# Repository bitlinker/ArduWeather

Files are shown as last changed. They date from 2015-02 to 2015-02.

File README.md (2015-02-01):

# ArduWeather
Yet another Arduino weather station project

This project is heading to create the portable device for measuring temperature, humidity and atmospheric pressure inside and outside the house and share that data using USB serial interface.

## Hardware
The hardware used:
* [Arduino](http://arduino.cc/en/Main/ArduinoBoardUno) compatible board (I used Arduino UNO)
* BMP085 pressure sensor with current-limiting resistors
* DHT22 temperature-humidity sensor
* 433 MHz Wireless Receiving Module for Oregon Scientific wireless sensors

The wiring is shown on the image below:
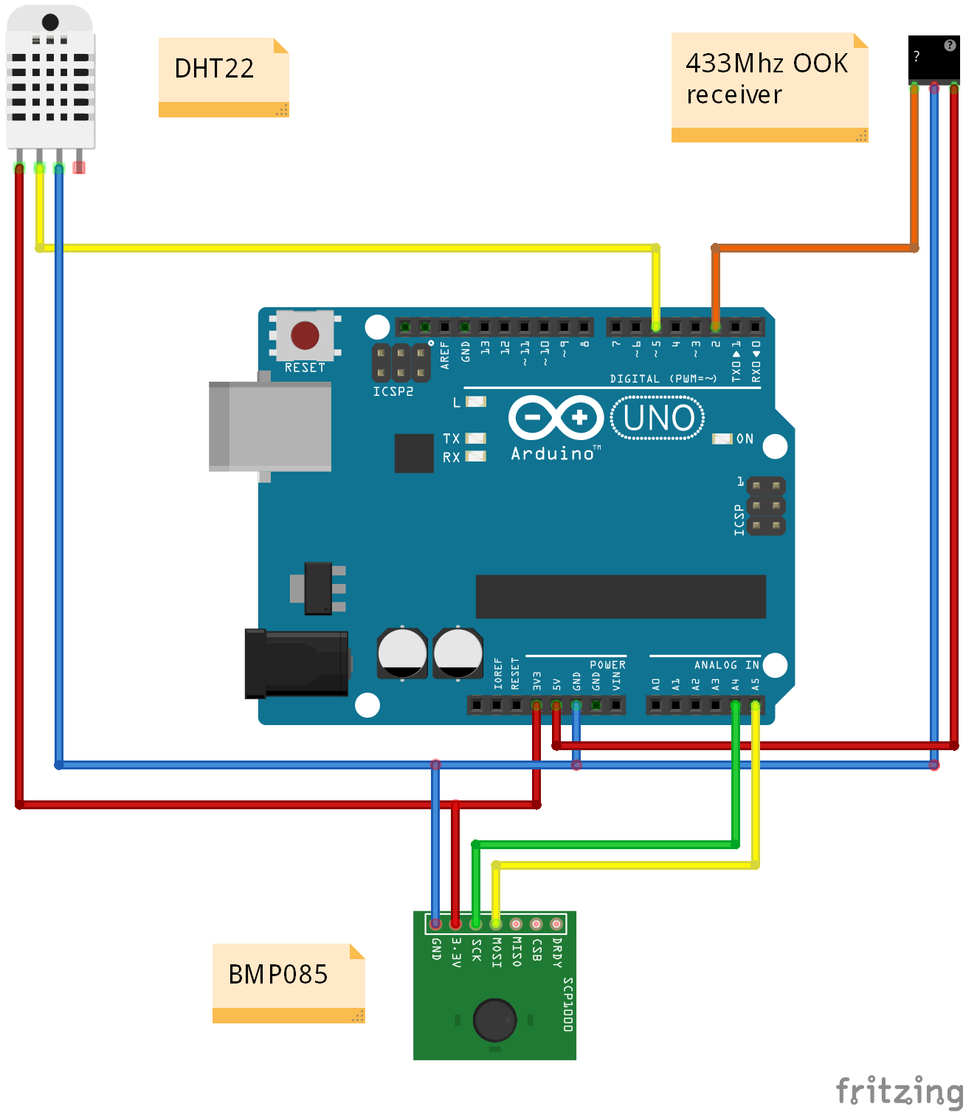
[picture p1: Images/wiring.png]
Wiring


The DHT22 is powered by 5V and it's data out pin is connected to the Arduino D5 pin.
The BMP085 is powered by 3.3V, SDA is connected to A4 and SCL is connected to A5 - hardware I²C bus is used.
The receiver is powered by 5V and connected to D2 - hardware interrupt is used

The 17.3cm wire should be used for antenna on 433 Mhz. It's enough to get good signal from wireless sensor about 15m away blocked by 2 walls. The old modem casing was used. There are some photos of assembled device:
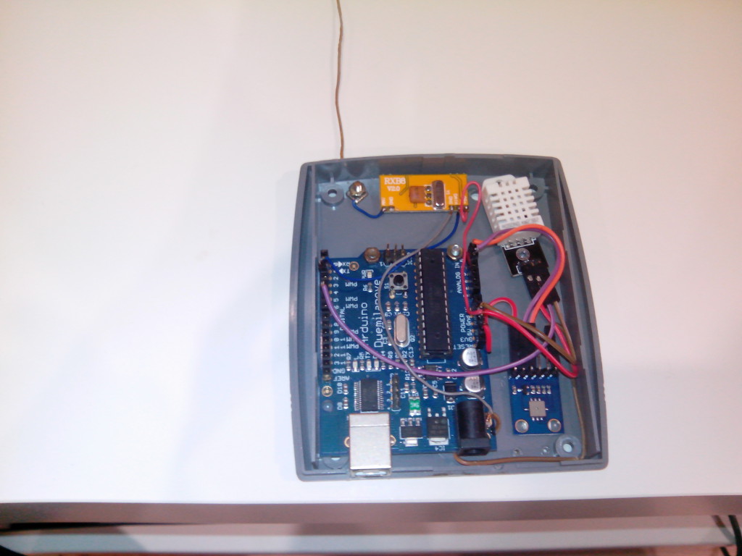
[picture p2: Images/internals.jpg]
Device internals

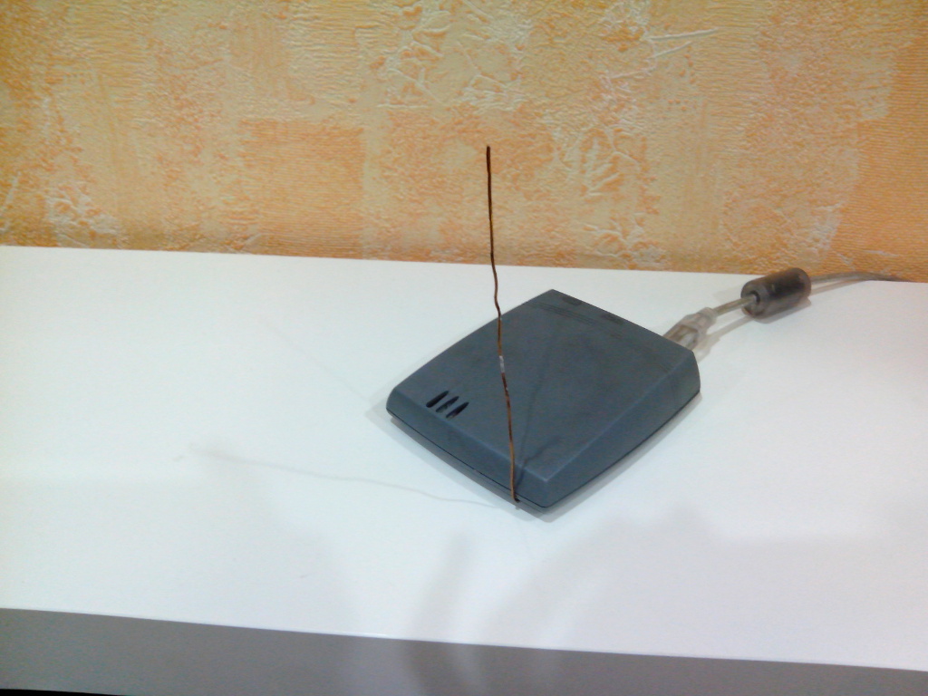
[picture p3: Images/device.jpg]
Assembled device


## Software
The Arduino firmware could be found in repository. The following libraries were used:
* [Adafruit_BMP085](https://github.com/adafruit/Adafruit-BMP085-Library)
* [DhtLib](http://playground.arduino.cc/Main/DHTLib)
* [TimerOne](http://playground.arduino.cc/Code/Timer1) - it was not really necessary, however really convenient.
* [ookDecoder](https://github.com/jimstudt/ook-decoder) - the version in repository was **patched** to work sucessfully with cheap chinese receivers which could pass initial bits from preamble.

NarodmonDaemon software is written in Python and used to read data from device and publish it to the [Public Monitoring](http://narodmon.ru/) project. It could be configured by Config.py file.

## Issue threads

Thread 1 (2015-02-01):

Support Oregon data filtering

bitlinker, 2015-02-01:
Support data filtering for Oregon Scientific sensors, so the sensor data will be used only if it updated 2 or more times. For now, it's possible to get wrong readings because of radio IO errors

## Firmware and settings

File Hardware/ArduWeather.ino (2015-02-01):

/**
* Copyright (c) 2015 bitlinker@gmail.com
* 
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
* THE SOFTWARE IS PROVIDED "AS IS", WITHOUT WARRANTY OF ANY KIND, EXPRESS OR
* IMPLIED, INCLUDING BUT NOT LIMITED TO THE WARRANTIES OF MERCHANTABILITY,
* FITNESS FOR A PARTICULAR PURPOSE AND NONINFRINGEMENT. IN NO EVENT SHALL THE
* AUTHORS OR COPYRIGHT HOLDERS BE LIABLE FOR ANY CLAIM, DAMAGES OR OTHER
* LIABILITY, WHETHER IN AN ACTION OF CONTRACT, TORT OR OTHERWISE, ARISING FROM,
* OUT OF OR IN CONNECTION WITH THE SOFTWARE OR THE USE OR OTHER DEALINGS IN
* THE SOFTWARE.
*/

#include <TimerOne.h>
#include <Wire.h>
#include <OregonDecoder.h>
#include <dht.h>
#include <Adafruit_BMP085.h>

#include <SoftwareSerial.h>

#define LED 13 // LED on D13

#define OREGON_PIN 2  // D2 - using hardware level change interrupt
#define DHT22_PIN 5   // D5 - DHT22 thermo/humidity
// BMP085 is on A4 and A5 pins

#define LOCAL_SENSORS_UPDATE_TIMEOUT 10000000 // us

#define DEVICE_NAME "ArduWeather 1.0"

OregonDecoderV2 orscV2;
dht dhtReader;
Adafruit_BMP085 bmpReader;

volatile word pulse = 0;
volatile bool isLocalReportTimeout = false;

// Oregon receiver interrupt
void oregon_int(void)
{
    static word last = micros();
    pulse = micros() - last;
    last += pulse;
}

// Timer interrupt
void local_timeout_int(void)
{
    isLocalReportTimeout = true;
}

void printProtocolHeader() {
    Serial.print("{");

    // Device name and version
    Serial.print("\"device\":\"");
    Serial.print(DEVICE_NAME);
    Serial.print("\",");

    // Sensors array start
    Serial.print("\"sensors\":[");
}

void printProtocolFooter() {
    // Sensors array end and closing bracket
    Serial.println("]}");
}

void reportLocal()
{
    printProtocolHeader();

    // DHT22
    if (dhtReader.read22(DHT22_PIN) == DHTLIB_OK)
    {
        Serial.print("{\"DHT22\":{\"H\":");
        Serial.print(dhtReader.humidity);
        Serial.print(",\"T\":");
        Serial.print(dhtReader.temperature);
        Serial.print("}},");
    }

    // BMP085
    Serial.print("{\"BMP085\":{\"T\":");
    Serial.print(bmpReader.readTemperature());
    Serial.print(",\"P\":");
    Serial.print(bmpReader.readPressure());
    Serial.print("}}");

    printProtocolFooter();
}

void reportOregon ()
{
    printProtocolHeader();

    Serial.print("{\"oregon\":{\"data\":\"");
    byte pos;
    const byte* data = orscV2.getData(pos);
    for (byte i = 0; i < pos; ++i)
    {
        Serial.print(data[i] >> 4, HEX);
        Serial.print(data[i] & 0x0F, HEX);
    }
    Serial.print("\"}}");

    printProtocolFooter();
}

void setup ()
{
    Serial.begin(115200);

    // Oregon
    pinMode(OREGON_PIN, INPUT);
    digitalWrite(OREGON_PIN, HIGH);
    attachInterrupt(0, oregon_int, CHANGE);

    // LED
    pinMode(LED, OUTPUT);

    // BMP085
    if (!bmpReader.begin())
    {
        digitalWrite(LED, HIGH); // Error
        while (1) {}
    }

    // Local sensors update timer
    Timer1.initialize(LOCAL_SENSORS_UPDATE_TIMEOUT);
    Timer1.attachInterrupt(local_timeout_int);
}


void loop ()
{
    noInterrupts();
    word p = pulse;
    pulse = 0;
    interrupts();

    if (isLocalReportTimeout)
    {
        digitalWrite(LED, HIGH);
        reportLocal();
        isLocalReportTimeout = false;
        digitalWrite(LED, LOW);
    }

    // Oregon sensors
    if (p != 0)
    {
        if (orscV2.nextPulse(p))
        {
            digitalWrite(LED, HIGH);
            reportOregon();
            orscV2.resetDecoder();
            digitalWrite(LED, LOW);
        }
    }
}

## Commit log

2014-12-20 Initial release
    [Wiring.fzz]
2015-02-01 Updated license, folders structure
    [Wiring.fzz]
2015-02-01 Added required imports - fix to run on Linux environment
    [main.py]
